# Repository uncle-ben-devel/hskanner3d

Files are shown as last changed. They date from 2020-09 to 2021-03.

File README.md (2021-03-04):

<p align="center">
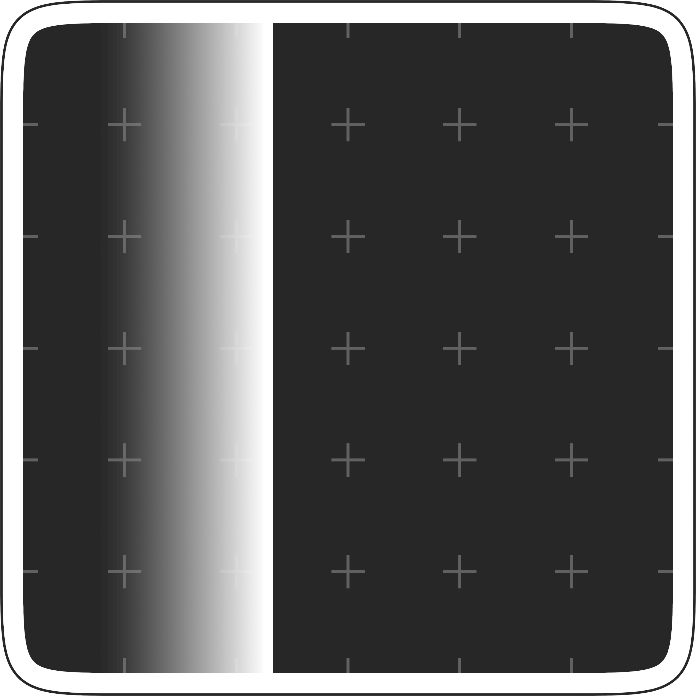
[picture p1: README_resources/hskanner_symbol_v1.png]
  
</p>

# HSkanner3D
3D scanning using a network of Raspberry Pies with camera modules and photogrammetry. This project is funded and overseen by Hochschule Karlsruhe - Technik und Wirtschaft and developed by Benedikt Reinberger. It involves the design and assembly of a complete 3D scanner (hardware and software). If you want to build your own, this may be a good starting point.

## HSkanner3D system architecture
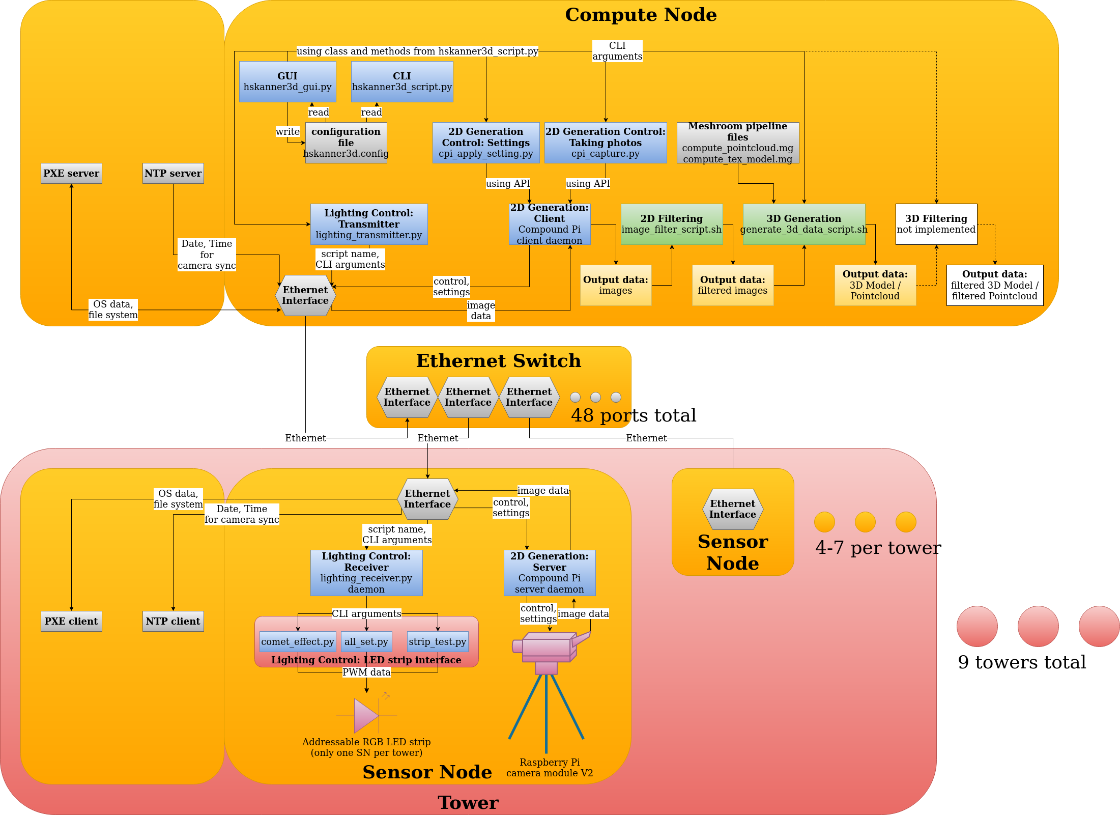
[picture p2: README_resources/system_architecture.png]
HSkanner3D system architecture


## The Scanner in the Lab in Karlsruhe
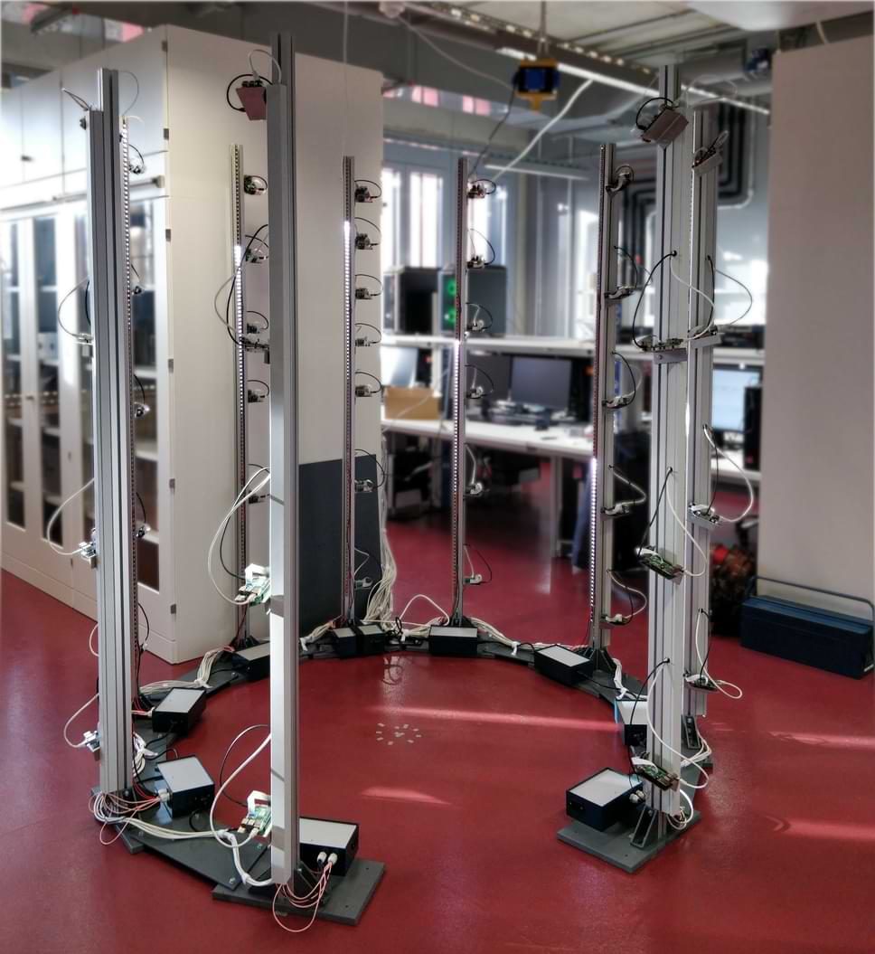
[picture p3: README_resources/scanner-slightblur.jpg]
HSkanner3D camera array


# Setup
## Hardware
To run your own instance of HSkanner3D or to set it up from scratch, first gather the required hardware.

*   PC with NVidia graphics card (needed for photogrammetry software Meshroom, uses CUDA exclusively)
*   keyboard, mouse, monitor for interfacing with the PC
*   one or more Raspberry Pi 4, Model B
*   one SD card, 16GB is plenty
*   one or more ethernet cable(s)
*   an ethernet switch with at least one interface for each Raspberry Pi and the PC (unmanaged is fine)

## Naming Conventions
First, some naming conventions.

*   the PC will run computation of the 3D model, so it is the compute node (**CN**)
*   the PC will run networking and camera array control, so it also is the array server (**AS**)
*   the Raspberry Pies will be connected to the camera sensors and are used to interface the cameras to the network, so they are sensor nodes (**SN**)
*   the SN are attached to metal structures to keep them suspended at a calculated height and angle. The metal structures are called **tower**s.
*   for each tower, there is one SN controlling the RGBW led strip for lighting and light effects. That one also is a lighting node (**LN**).

# Expert Installation Guide
*   install Ubuntu 18.04 on the PC.
*   install the required software by running
```
    sudo add-apt-repository -y ppa:waveform/ppa && sudo apt-get update && sudo apt-get install -y git meshlab python3-tk ntp python-pip python3-pip python3.7 compoundpi-client && pip install setuptools
```
*   set up the NTP server by running
```
    echo "broadcast 192.168.128.255" | sudo tee -a /etc/ntp.conf
    echo "server 127.127.1.0" | sudo tee -a /etc/ntp.conf
    echo "fudge 127.127.1.0 stratum 10" | sudo tee -a /etc/ntp.conf
```
*   then, edit /etc/ntp.conf to remove the "limited" option from the lines
```
    restrict -4 default kod notrap nomodify nopeer noquery limited
    restrict -6 default kod notrap nomodify nopeer noquery limited
    ->
    restrict -4 default kod notrap nomodify nopeer noquery
    restrict -6 default kod notrap nomodify nopeer noquery
```
*   from this repo, execute
```
    /installation_setup/pxe_setup/pxe_setup_script_static.sh
```
*   download RaspiOS buster lite armhf 2020-02-13 (2020-12-04 will work, too), then flash it to a micro SD card.
*   copy bootloader-flash-utils and cpi_setup from  the /installation_setup directory of hskanner3d to /home/pi on the rootfs.
*   then, copy over the 00_lighting_control directory from the /processing_chain of hskanner3d.
*   on the Raspberry Pi, execute
```
    /bootloader-flash-utils/flash_bootloader.sh
```
*   to flash the bootloader to one that can boot PXE. This script is made for automation. Add a cron job @reboot if you want to flash multiple Raspberry Pies headless.
*   make sure you have internet access on the Pi, then execute
```
    /cpi_setup/cpi_server_SN_setup.sh
```
*   then install the software required for the lighting to work using
```
    sudo apt-get install -y python3-pip python3.7 python3-rpi.gpio
    sudo pip3 install adafruit-circuitpython-neopixel rpi_ws281x
```
*   to enable the lighting control at boot, run
```
    crontab -e
```
*   and add
```
    @reboot sudo python3.7 /home/pi/00_lighting_control/lighting_receiver.py
    @reboot sudo service ntp stop && sudo ntpd -gq && sudo service ntp start
```
*   or equivalent, then save and exit.
*   enable the camera interface on the Pi.
*   mount the micro SD card on the PC and execute
```
    /installation_setup/pxe_setup/pxe_refresh_OS.sh
```
*   look at the config file in /processing_chain and modify the variables to suit your needs (keeping the data types).
*   reboot the PC
*   connect and power up the Raspberry Pies.
*   start the GUI from /processing_chain using python3.7.

# Beginner Installation Guide
## Operating System Setup
The HSkanner3D software is designed around the linux family of operating systems, thus we will be installing a linux distro on our PC to turn it into the CN and AS.

*   go to [the download page for Ubuntu 18.04](https://releases.ubuntu.com/18.04) and download the Ubuntu 18.04 .iso (HSkanner3D is known to work with Ubuntu 18.04 - other distros or versions may work, but 18.04 has all the majority of required software in the repositories or otherwise easily accessible). I recommend Ubuntu because it has the option to easily install and run the proprietary NVidia driver, which is needed for smooth operation.
*   on Windows, download [Rufus](https://rufus.ie/downloads/) or a similar tool and use it to flash the .iso to a USB medium from which we'll boot and install the OS.
*   on Linux, you can use dd to flash the .iso to an external installation medium using
```
    sudo dd if=/path/to/iso/name_of_iso.iso  of=/dev/sdx status=progress bs=4096 conv=fsync
    #    /dev/sdx should be substituted for the drive you want to flash the .iso to. Note that all partitions from that drive have to be unmounted first for dd to work.
```
*   insert the newly created usb installation medium into the PC and boot from it (you can look up the function key for the boot menu of your motherboard in the manual, or go into the BIOS and use boot override if available).
*   follow the instructions of the installation.
*   you will likely want to make a clean install, erasing everything on the OS disk before installing the new OS. Make sure you backed up any important files or partitions you want to keep beforehand, using a tool like [Clonezilla](https://clonezilla.org/downloads.php) for partitions and OS installs, or just copying the files to external media. I chose the minimal install, but either one should be fine. You can leave the boxes for third parties and updates unticked, we will deal with those manually.
*   to make networking easier, I recommend getting internet into the PC by using a different network interface than the one connected to the scanning array. The easiest way to do this is to use a smartphone connected to the PC using USB tethering. To do that, on your smartphone running Android, go to Settings > Network and Internet > Hotspot and tethering and toggle the USB tethering option while the phone is connected to the internet by the means of WiFi. Note that you have to toggle it every time the PC is rebooted.
*   if you chose Ubuntu 18.04, you will have to manually enable the proprietary NVidia drivers after the first boot. Press the Windows (Super) key on the keyboard and type "Software & Updates" to search for it. Click on the first result and navigate to the "Additional drivers" tab, then select the latest proprietary driver and install it.
## Software Install on CN
*   now that we have internet access on the PC, it is time to install the software.
*   open a terminal by pressing the Windows (Super) key, then type "terminal". Click on the icon or press enter.
*   first, we will install git, a version control system I used when I developed the software. This will be used to download all the project files to the target machine. To do that, type
```
    sudo apt-get install -y git
```
*   into the terminal and press enter.
*   now that git is installed, we will download the project files by execution of
```
    git clone https://github.com/uncle-ben-devel/hskanner3d.git
```
*   this will create the development folder of the project on the PC at the home directory root. (/home/your-username-here/)
*   now you can open this file (README.md) in a text editor of your choice and copy the commands directly instead of typing them out. You can do that by selecting the text with the mouse, then mousewheel clicking inside the terminal.
*   install the required software by execution of the following line:
```
    sudo add-apt-repository -y ppa:waveform/ppa && sudo apt-get update && sudo apt-get install -y meshlab python3-tk ntp python-pip python3-pip python3.7 compoundpi-client && pip install setuptools 
    # meshlab: used as 3D data visualizer
    # python3-tk: python3 library for GUI development
    # ntp: service for time sync over the network
    # python-pip: source for python2.x software
    # python3-pip: source for python3.x software
    # python3.7: the version of python that is verified to work with all the involved software and scripts. Other versions may work, but are not tested.
    # compoundpi-client: part of the image capture software running on the AS.
```
*   enter the password if prompted.
*   we need additional software that is not provided within the Ubuntu packages. Namely, [Meshroom (Version 2019 2.0 is known to work)](https://www.fosshub.com/Meshroom-old.html). Download it using the provided link, then move the folder named 'Meshroom-2019.2.0-linux' to /home/your-username-here/Documents/software. If the directory does not exist yet, create it. Alternatively, you can move it wherever you like and change the meshroomroot variable in the hskanner3d.config file. If you choose to use a version of Meshroom that is different from 2019.2.0-linux, make sure to correct this path in the config file as well.
*   to add the Raspberry Pi camera module to the camera database, replace the cameraSensors.db that comes with Meshroom (/aliceVision/share/aliceVision) with the one from /installation_setup.
*   if you want to be able to open the design files (CAD and simulation), you will need [Freecad 0.19](https://github.com/FreeCAD/FreeCAD/releases/tag/0.19_pre) with the Assembly4 and SheetMetal workbenches (Freecad 0.18 will NOT work since it can not open multiple project files at once) and [Blender 2.90.0](https://github.com/blender/blender/releases/tag/v2.90.0) with the MDLab plugin and the [demo assets](https://github.com/animate1978/MB-Lab-DemoAssets).
*   to set up the array network, search for 'Network' and click on the one under the 'Settings' category. First, click on the gear by PCI Ethernet to get into the settings of the on-board ethernet. Under the 'IPv4' tab, select 'Manual' for IPv4 Method and enter 192.168.128.2 as Address, and 255.255.255.0 as Netmask. Leave the Gateway empty. Disable IPv6 in its tab by selecting the 'Disable' option for 'IPv6 Method'. Toggle the interface on and off to apply the new settings.
*   set up the NTP server by running
```
    echo "broadcast 192.168.128.255" | sudo tee -a /etc/ntp.conf
    echo "server 127.127.1.0" | sudo tee -a /etc/ntp.conf
    echo "fudge 127.127.1.0 stratum 10" | sudo tee -a /etc/ntp.conf
```
*   this will broadcast the time on the subnet 192.168.128.0/24. Additionally, if time can not be obtained from the internet, it will use the internal clock instead.
*   then, edit /etc/ntp.conf to remove the "limited" option from the lines
```
    restrict -4 default kod notrap nomodify nopeer noquery limited
    restrict -6 default kod notrap nomodify nopeer noquery limited
    ->
    restrict -4 default kod notrap nomodify nopeer noquery
    restrict -6 default kod notrap nomodify nopeer noquery
```
*   this will ensure that time will be synchronized even if there are more than three clients.
*   make sure the PC has internet connection. Then, to enable PXE (booting the SNs over network) on the PC (AS) side, go to /installation_setup/pxe_setup. Afterwards, rightclick in the directory and select 'open in terminal' and execute
```
    ./pxe_setup_script_static.sh
```
*   this script sets up a DHCP server, a PXE server, fixes some common issues, and lays the groundwork for the SN to be able to boot from the ethernet interface. The DHCP server gives IP addresses from 192.168.128.100 to 192.168.128.200 to its clients. Make sure to change that when you have more than one hundred SN.
## Software install on SN (and LN)
*   download [RaspiOS buster lite armhf, .zip file](https://downloads.raspberrypi.org/raspios_lite_armhf/images/raspios_lite_armhf-2020-12-04), then flash it to a micro SD card. I tested the 2020-12-04 as well as the 2020-02-13 version, and both work. To help making flashing using dd easier, you can use the 'Disks' utility in Ubuntu. First, unmount all partitions on the SD card by clicking on them and then on the sqare icon below the partitions. After that, you can format it by clicking on the three horizontal lines > Format Disk ... > Format ... > Format. You can also get the device lettering from here (/dev/sdX).
*   once it is flashed, open the file browser and navigate to /media/your-username-here/boot and create an empty file called 'ssh' by opening a terminal there and executing
```
    sudo touch ssh
```
*   this enables us to remote into the Raspberry, omitting the use of a screen and keyboard.
*   next, navigate to /media/your-username-here/rootfs/etc and execute
```
    sudo nano dhcpcd.conf
```
*   then, add the lines
```
    interface eth0
    static ip_address=192.168.128.10/24
```
*   to the end of the file to set a static IP for the Pi. This makes it much easier to remote into it. Save the changes with Ctrl + S, then exit the editor using Ctrl + X.
*   navigate to /media/your-username-here/rootfs/home/pi, then copy over bootloader-flash-utils and cpi_setup from  the /installation_setup directory of hskanner3d.
*   then, copy over the 00_lighting_control directory from the /processing_chain of hskanner3d.
*   after the files have been copied over, you can eject the SD card and insert it into the Raspberry Pi.
*   power up the Raspberry Pi and connect it to the network.
*   open up a terminal on the PC (AS), and connect to the Pi using ssh:
```
    ssh pi@192.168.128.10
```
*   the password is raspberry.
*   first, we need to flash a bootloader to the Pi that will allow it to boot over the network. To do that, go to the /bootloader-flash-utils directory using cd
```
    cd ~/bootloader-flash-utils
```
*   hint: you can use tab for autocompletion.
*   then, execute
```
    sudo ./flash_bootloader.sh
```
*   the system will reboot and sever the ssh connection. Reconnect to it. If you want to flash multiple Pies, add a cron job @reboot that executes the flashing script. It will flash, do the mandatory reboot, then shut down.
*   once you are reconnected, you'll need internet access for the Raspberry. You can use USB tethering again. Test for internet connection using
```
    ping www.google.com
```
*   if you can't reach it, the Pi likely tries to access the internet using the ethernet interface, the local network. To circumvent this, execute
```
    sudo ip route delete default
```
*   make sure you have internet access, then change directory (cd) to ~/cpi_setup, then execute
```
    ./cpi_server_SN_setup.sh
```
*   then install the software required for the lighting to work using
```
    sudo apt-get install -y python3-pip python3.7 python3-rpi.gpio
    sudo pip3 install adafruit-circuitpython-neopixel rpi_ws281x
```
*   to enable the lighting control at boot, run
```
    crontab -e
```
*   and add
```
    @reboot sudo python3.7 /home/pi/00_lighting_control/lighting_receiver.py
    @reboot sudo service ntp stop && sudo ntpd -gq && sudo service ntp start
```
*   or equivalent, then save and exit. The second line is to force a NTP synchronization at boot which is required for compound pi synchronized capture.
*   next, we will remove the static IP we set for easy SSH. Execute
```
    sudo nano /etc/dhcpcd.conf
```
*   and delete the last two lines we added earlier.
*   enable the camera interface using
```
    sudo raspi-config
```
*   and navigating to Interfaces > Camera > enable
*   we can now shut down the Raspberry Pi using
```
    sudo shutdown now
```
*   and remove the micro SD card.
## Last steps for PXE booting
*   insert the SD card into the PC. Then, navigate to the /installation_setup/pxe_setup directory from hskanner3d and execute
```
    ./pxe_refresh_OS.sh
```
*   this script backs up the current OS setup, then takes the OS install from a SD card and copies it onto the local disk. Afterwards, it formats it in a way that wakes it compatible with network booting.
*   After the script has been executed, reboot. You can also remove the SD card now.
*   Powercycle the Raspberry Pi AFTER the PC has booted and been running for a little while. It should now boot from the network. To verify, execute
```
    cat /var/lib/misc/dnsmasq.leases
```
*   if there is no output, nothing has happened (yet). If everything goes smooth, the third field will have an IP address that was assigned to a Pi. The third field will say "raspberrypi" (the hostname of the device). The green status LED of the Pi should cycle between blinking fast twice, and pausing for about a second after it has booted with PXE. The boot may take a while (sometimes minutes), depending on the order the bootloader looks for PXE files on the network share.
# Using HSkanner3D
*   look at the config file in /processing_chain and modify the variables to suit your needs (keeping the data types).
```
The [default] section provides defaults for all other sections. It is loaded by pressing the "load defaults" option in the GUI.
The [custom] section is loaded on GUI startup and is used as persistant storage for the user settings.
    meshroomroot        is the complete path from filesystem root to the root of meshroom (the first folder that contains files other than a single folder)
    pipe_file_hq        is the name of the meshroom pipeline file that will be used when the "high quality" option for computation is chosen in the GUI.
    pipe_file_fast      same as pipe_file_hq, but for the "fast" option.
    number_sensor_nodes the number of Raspberry Pies attached to the scanning array. This is used by compoundpi to stop scanning for more servers when the defined number of SN has been found. If the number of SN in the array is lower than this variable, compound pi will throw an assertion error.
    network_subnet      is the local network we use for the scanning array, in CIDR-notation. It's recommended you don't change this, since this is not the only place you would need to change IP addresses to use a different network for the scanner. Read the setup if you want to look where IP addresses and ranges are set for this application.
    shutterspeed        is the shutterspeed of the Raspberry Pi camera module to be used. It is set in milliseconds and invalid values will result in the camera module using its default value. Since we want to scan humans, 1/50s...1/60s is a decent shutter speed.
    isosetting          is the ISO value of the camera module. Invalid values will result in the camera module using the highest or lowest possible setting (depending on whether you over- or undershot it), but writing the set ISO to the image metadata.
    whitebalance        is the whitebalance setting of the camera module. auto works well. If set values like tungsten are set, different camera modules will still have different color temperature in the end, with auto this problem is less visible.
    selftimer           is additional wait time in seconds before the shot is taken. It takes more time from pressing an action button (take images, 3d scan, ...) to the actual capture because of program overhead and general slowness of compoundpi. If selftimer is 0.0, the captures are not synchronized (on purpose) - the cameras will fire as soon as possible. That is usually good enough for a 3D scan of a human. One disadvantage of synced capture is that the clock of SN and AS need to be in sync, and there is no apparent way to easily check for that. Since the capture timing is set from the AS, it sets a timestamp at current time + selftimer time. If the SN are one hour behind, it will take one hour until a capture will happen. Don't set the selftimer too short (smaller than 0.1s), because Compound Pi will not be fast enough to react, yielding the error message 'Timestamp is in the past'. A value of 1.0s is usually a good time for decently fast reaction times with sync ong.
    rotation            rotation of the captured images in increments of 90 (degree). It's not required to rotate the images for Meshroom, it does not care. However, it is nicer to look at for humans.
    openfilebrowser     can be either 1 or 0 (enabled and disabled). If it's enabled, a file browser will open after image capture and the user can open the images to observe the captured material.
    view_mesh           can be either 1 or 0 (enabled and disabled). If it's enabled, Meshlab will open the generated 3D data for visualization after generation.
    strip_length        is the number of LEDs contained in a LED strip of a single tower.
    comet_tail_length   is length of in number of LEDs the comet effect (scanner idle decorative lighting) will have, minus one (the leading LED, the "comet").
    comet_brightness    is the brighness of the comet effect LEDs and can be from 0.0 to 1.0
    comet_r/g/b/w       are the color values of the comet, integers from 0 to 255.
    comet_sleeptime     is waiting time in seconds in between instances of the animation loop and thus defines how fast the effect will run through the strip.
    photo_light_r/g/b/w are the color values the LED strips will assume before and while taking photos, integers from 0 to 255.
```
*   now you can execute the GUI in a terminal or create a desktop shortcut (or modify the one supplied with the repo). The buttons and tabs of the GUI should be self-explanatory.
```
    python3.7 $HOME/hskanner3d/processing_chain/hskanner3d_gui.py
```

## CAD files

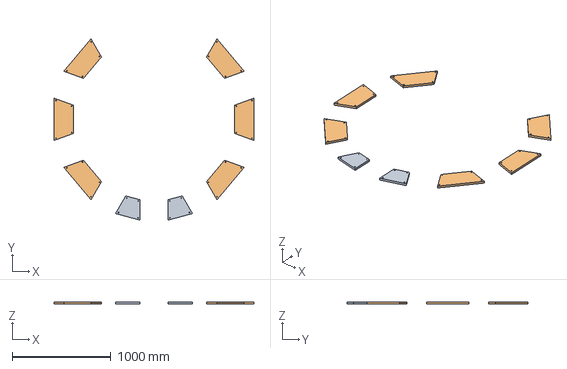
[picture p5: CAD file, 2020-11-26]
design/towers_scanner_cad/asm-array.FCStd
2030.3 x 1841.3 x 20.0 mm

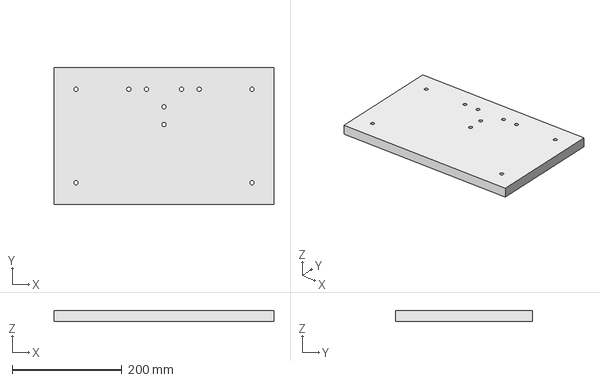
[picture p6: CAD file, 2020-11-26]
design/towers_scanner_cad/tower-parts.FCStd
400.0 x 250.0 x 20.0 mm

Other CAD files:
design/towers_scanner_cad/asm-tower-5c.FCStd
design/towers_scanner_cad/asm-tower-7c.FCStd
design/towers_scanner_cad/asm-tower-0c.FCStd
design/towers_scanner_cad/asm-tower-4c.FCStd
design/towers_scanner_cad/asm-tower-6c.FCStd

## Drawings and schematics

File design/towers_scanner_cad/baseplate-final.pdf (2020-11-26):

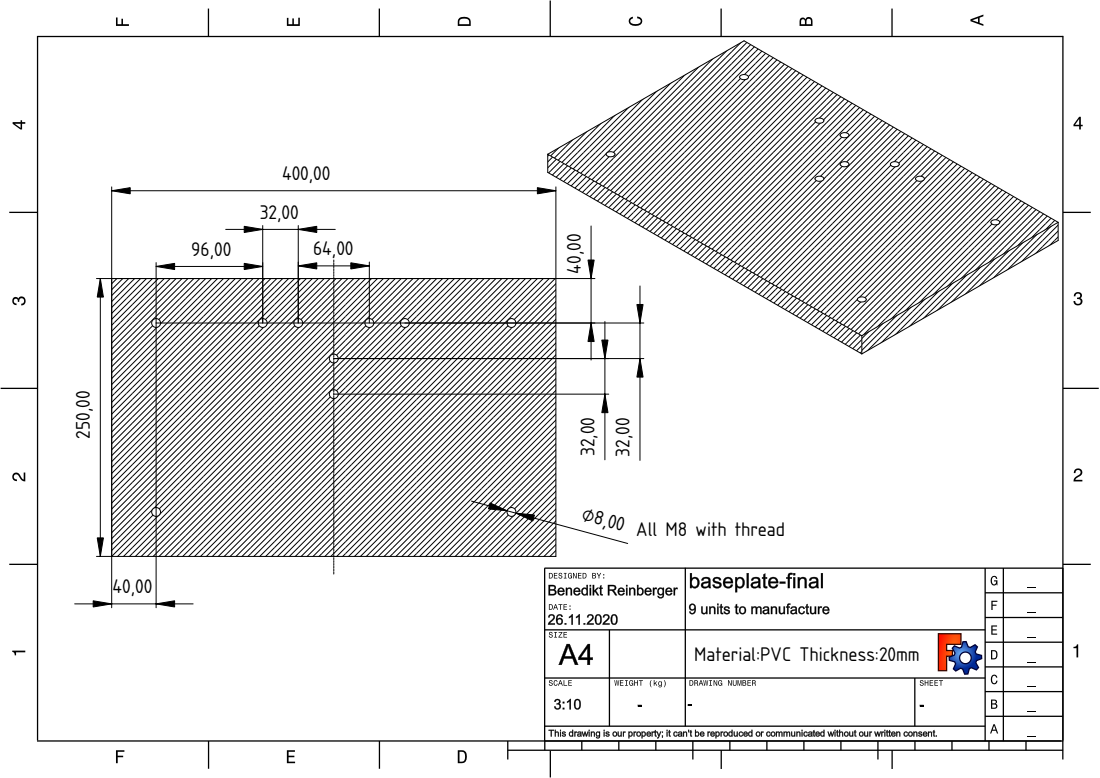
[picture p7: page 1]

⌀8,00 All M8 with thread

Material:PVC Thickness:20mm

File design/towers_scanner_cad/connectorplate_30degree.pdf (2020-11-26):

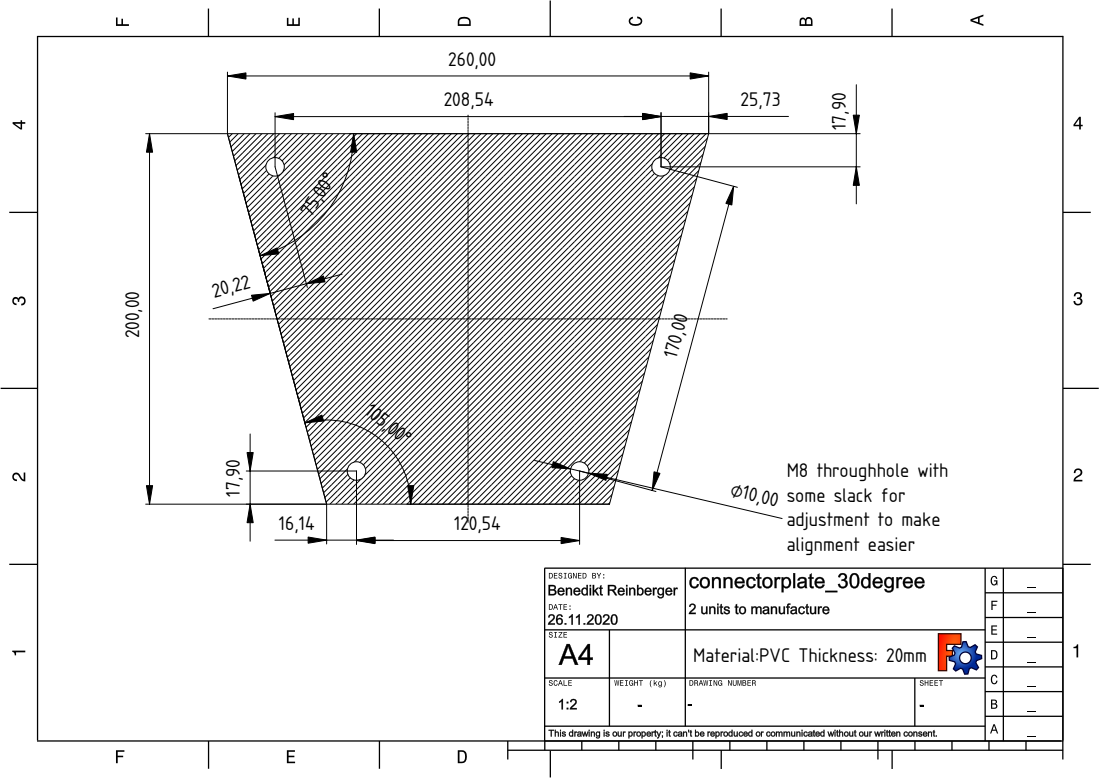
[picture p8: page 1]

M8 throughhole with
some slack for
adjustment to make
alignment easier

Material:PVC Thickness: 20mm

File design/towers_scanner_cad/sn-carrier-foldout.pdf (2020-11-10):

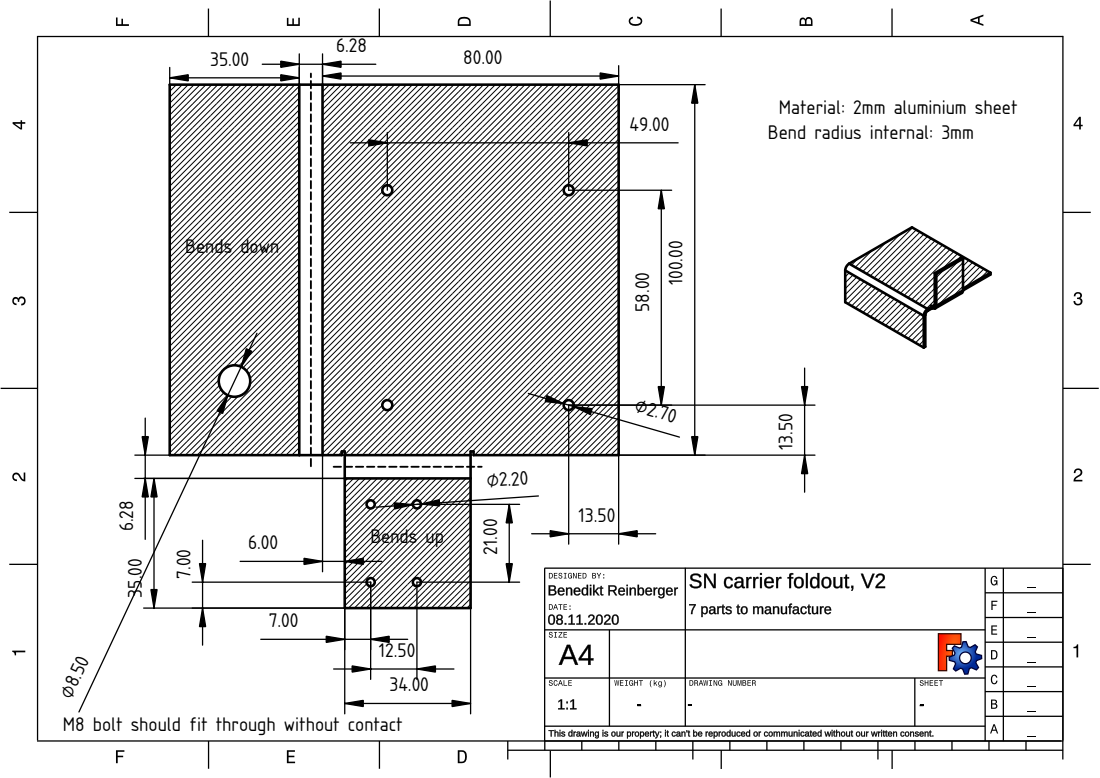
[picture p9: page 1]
Bends down; Bends up

Material: 2mm aluminium sheet
Bend radius internal: 3mm

M8 bolt should fit through without contact

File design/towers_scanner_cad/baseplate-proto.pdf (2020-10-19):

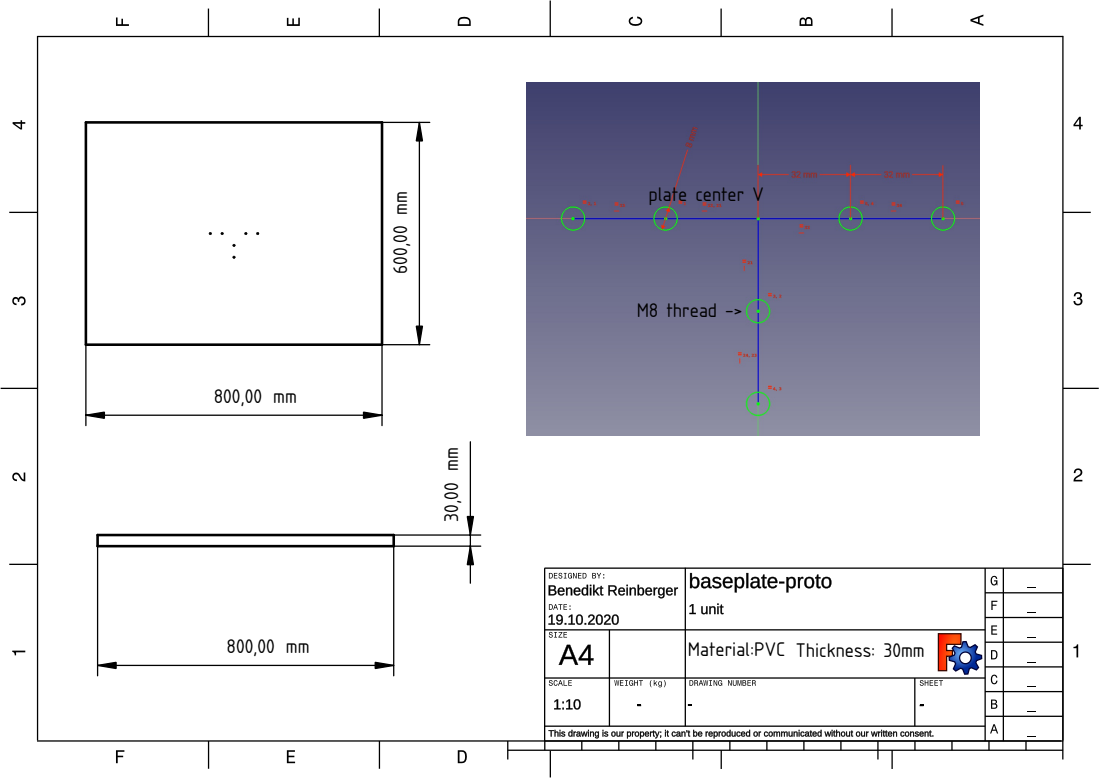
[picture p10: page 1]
M8 thread ->; plate center V

Material:PVC Thickness: 30mm

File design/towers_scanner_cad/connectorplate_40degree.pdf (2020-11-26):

4

3

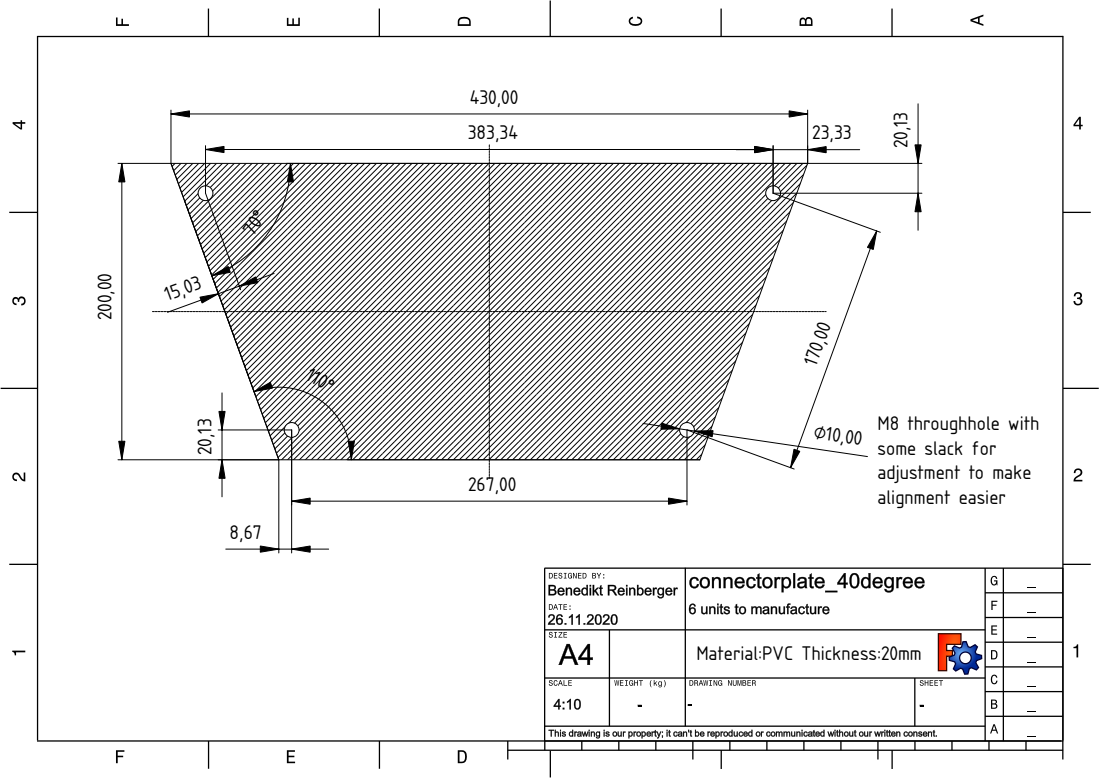
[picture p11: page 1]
aterial:P V; hick; 8 thro; h ole; with; slack for adjustment to m; alig n; sier

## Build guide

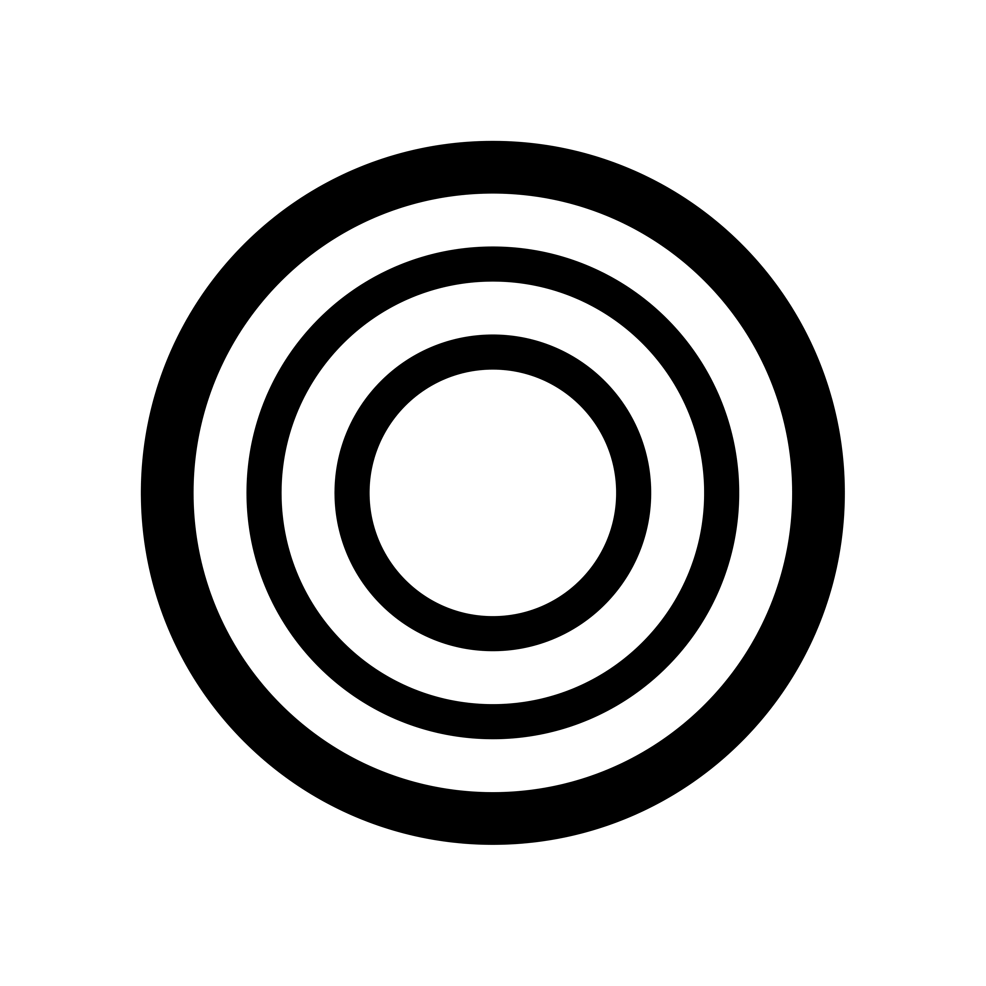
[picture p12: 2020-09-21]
design/position_estimation/CCTAGmarkersToPrint/00027-1.png

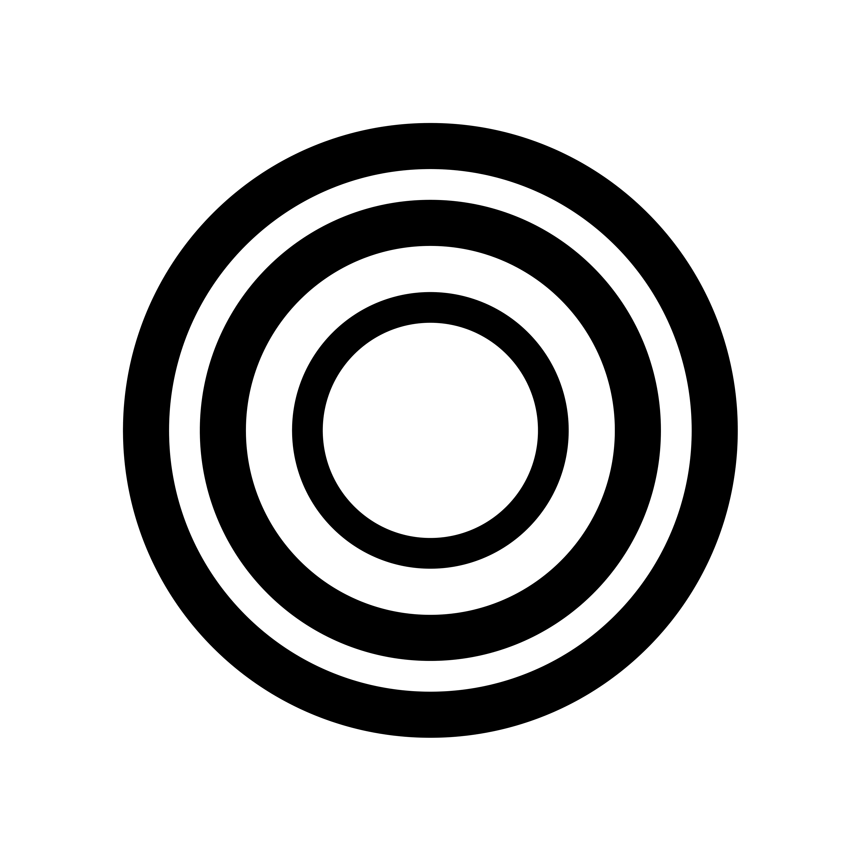
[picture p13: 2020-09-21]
design/position_estimation/CCTAGmarkersToPrint/00023-1.png

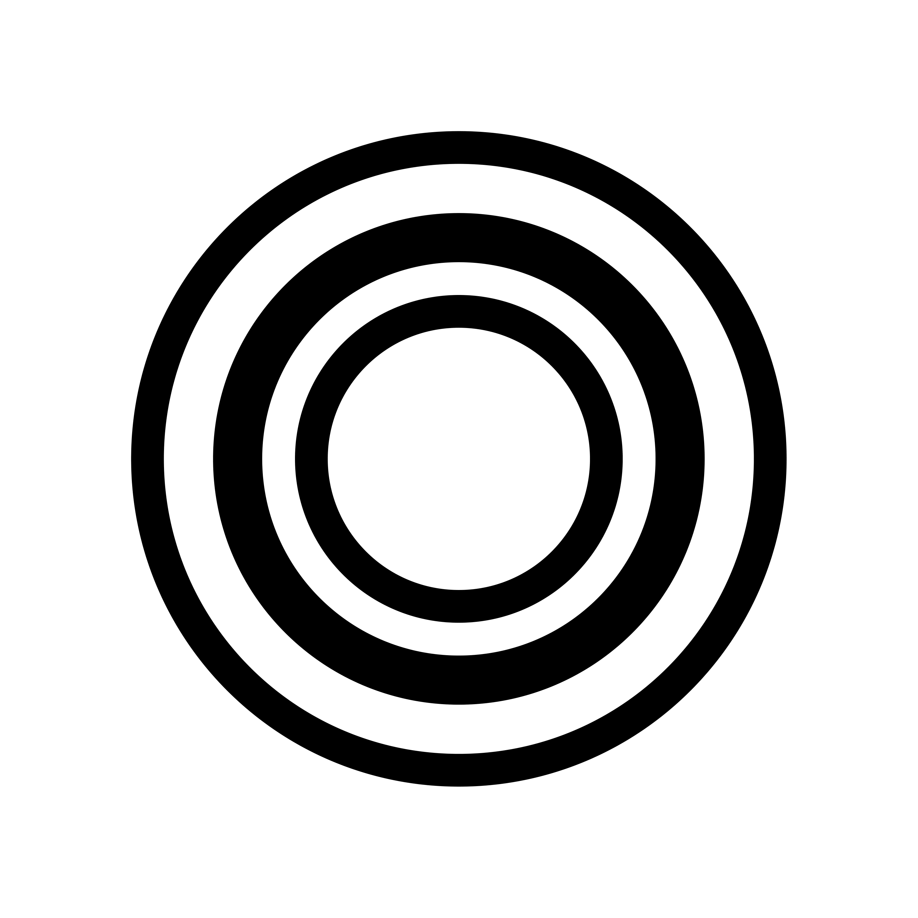
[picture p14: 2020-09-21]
design/position_estimation/CCTAGmarkersToPrint/00013-1.png

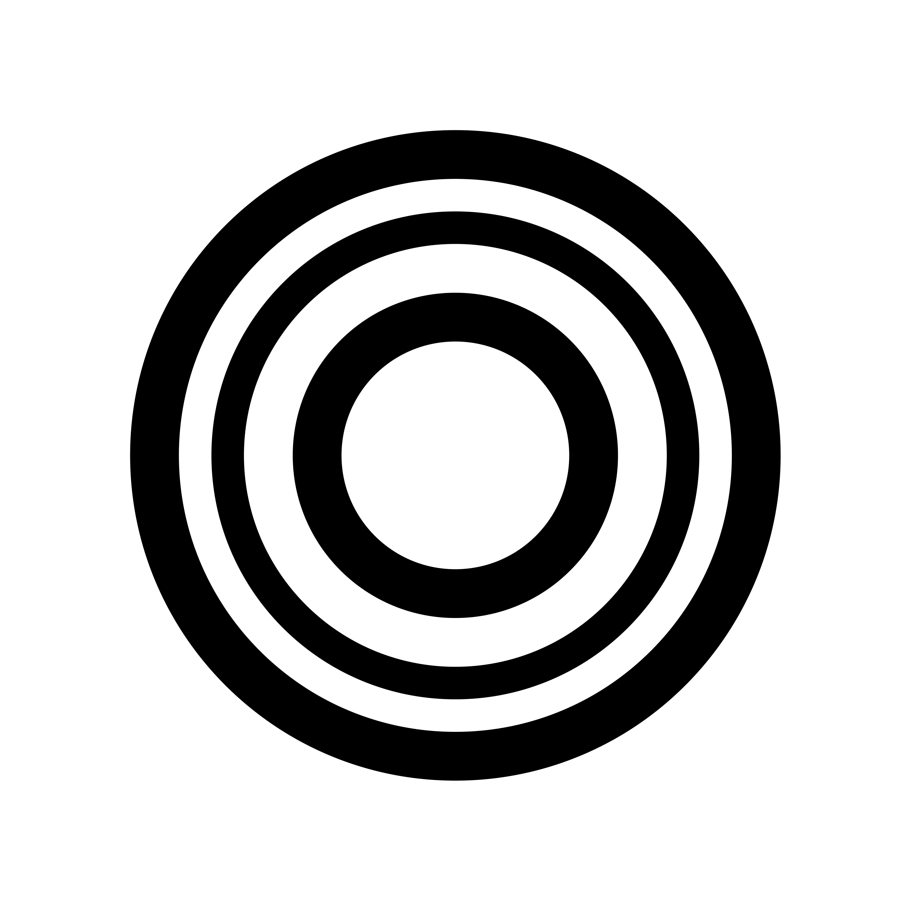
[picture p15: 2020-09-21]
design/position_estimation/CCTAGmarkersToPrint/00020-1.png

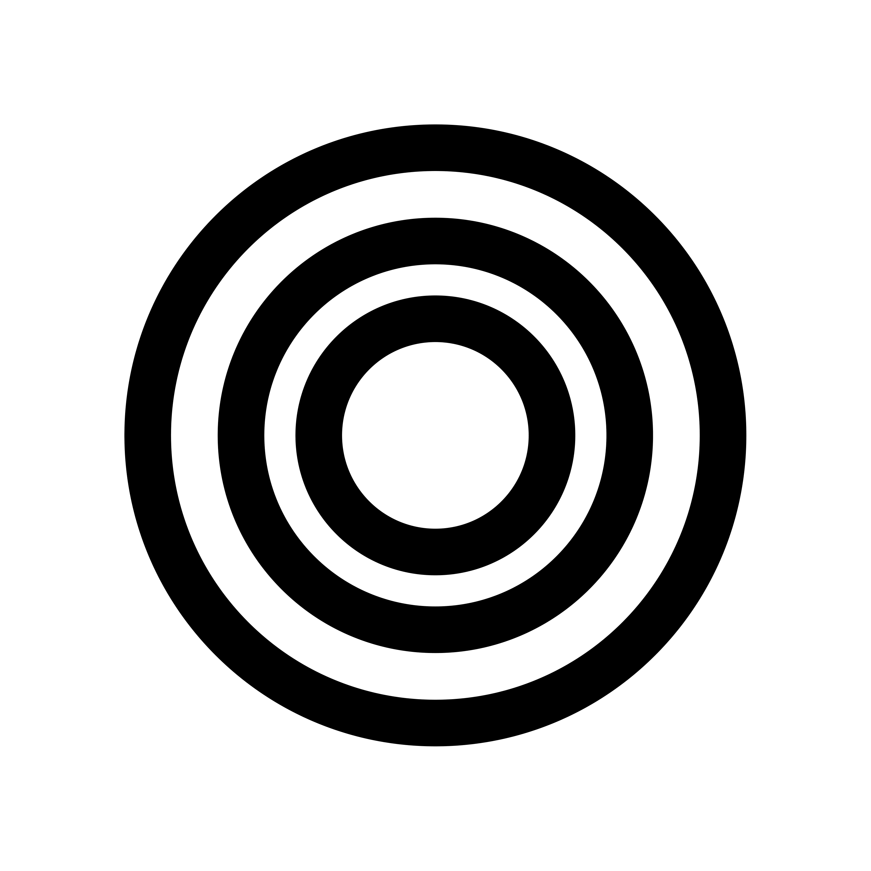
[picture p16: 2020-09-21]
design/position_estimation/CCTAGmarkersToPrint/00030-1.png

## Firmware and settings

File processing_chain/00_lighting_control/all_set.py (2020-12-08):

# Purpose
#   This script controls an RGBW-Strip with the data_in line attached to GPIO 18 on a Raspberry Pi.. All LEDs will be at the same user defined values.
####
# Usage
#   python3.7 all_set.py <int red_value> <int green_value> <int blue_value> <int white_value> <int number_leds>
#   color values can be 0...255 only.
#!/usr/bin/env python

import board
import neopixel
from sys import argv

# LED strip configuration:
LED_COUNT   = int(argv[5])      # Number of LED pixels.
LED_PIN     = board.D18      # GPIO pin
LED_BRIGHTNESS = 1
LED_ORDER = neopixel.GRBW # order of LED colours. May be GRB, RGB, GRBW, or RGBW

# Create NeoPixel object with appropriate configuration.
strip = neopixel.NeoPixel(LED_PIN, LED_COUNT, brightness = LED_BRIGHTNESS, auto_write=False, pixel_order = LED_ORDER)

strip.fill((int(argv[1]),int(argv[2]),int(argv[3]),int(argv[4])))
strip.show()

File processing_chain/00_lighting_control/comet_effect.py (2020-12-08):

# Purpose
#   This script controls an RGBW-Strip with the data_in line attached to GPIO 18 on a Raspberry Pi. It is used as the idle state of the LED strips and serves purely cosmetic purpose. It will run a tail of a  user defined length across the LED strip, using a user defined speed, color and brightness. The tail gets dimmer from origin to end.
####
# Usage
#   python3.7 comet_effect.py <int led_count> <int tail_length> <float led_brightness> <int red_value> <int green_value> <int blue_value> <int white_value> <float sleeptime>
#   color values can be 0...255 only. Sleeptime is additional wait time after each moving operation and is meant to slow the moving operation down.

#!/usr/bin/env python

from time import sleep
from sys import argv
import board
import neopixel

# LED strip configuration:
LED_COUNT   = int(argv[1])      # Number of LED pixels.
tail_len = int(argv[2]) # the tail will consist of tail_len-1 leds, with one led leading with 100% of what was set for the rgb values.
LED_PIN     = board.D18      # GPIO pin
LED_BRIGHTNESS = float(argv[3])  # LED brightness
LED_ORDER = neopixel.GRBW # order of LED colours. May be GRB, RGB, GRBW, or RGBW
# effect config
comet_r = int(argv[4])
comet_g = int(argv[5])
comet_b = int(argv[6])
comet_w = int(argv[7])
sleeptime = float(argv[8])    # change this value to adjust the speed of the effect. 0 is no wait in between cycles.

# Create NeoPixel object with appropriate configuration.
strip = neopixel.NeoPixel(LED_PIN, LED_COUNT, brightness = LED_BRIGHTNESS, auto_write=False, pixel_order = LED_ORDER)

strip.fill((0,0,0,0))   # clear strip before use

# Calculate all values for the LEDs just once. After that, it can be used as a shift register.
def comet_init(tail_len):
    for jj in range(tail_len):
        cc = (tail_len - jj) / (tail_len * (jj + 1))  # brightness factor for tail. Since brightness does not scale linearly, i chose (n-x)/(n*(x+1)) for scaling, where n is the tail length and x is the distance from the brightest LED.
        strip[jj % LED_COUNT] = (int(comet_r*cc),int(comet_g*cc),int(comet_b*cc),int(comet_w*cc))

# Shift register shifting (MSB: strip[0], shifts to the left)
def comet_loop():
    global strip    # needs to be global for us to be able to address it. Passing it to the function does not really work - I tried that first.
    buf = strip[0]
    strip[0:LED_COUNT-1] = strip[1:LED_COUNT]   # weird python adressing. why not ([0:LED_COUNT-2] and [1:LED_COUNT-1]?)
    strip[LED_COUNT-1] = buf
    strip.show()

# this try-finally construct allows for controlled behaviour when we kill the script. The script runs in a permanent loop, and blocks other scripts from controlling the LEDs. So if we want to do something different with the LED strip, we kill this script and execute another.
try:
    comet_init(tail_len)
    while True:
        comet_loop()
        sleep(sleeptime)        
finally:
    strip.fill((0,0,0,0))
    strip.show()

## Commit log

2020-09-03 Cleaned up the bash scripts, Updated paths and working directory
    [mesh.obj, texturedMesh.obj]
2020-09-03 Configured .gitignore with i/o directories
    [mesh.obj, texturedMesh.obj]
2020-09-07 Added precise camera information to the sensors database, and changed fov to 79d since that is the diagonal fov of the sensor module v2. Accuracy of the scanning improved DRAMATICALLY
2020-09-14 Added Blender Project folder for camera and lighting placement
2020-09-21 Tested new camera heights with the 9T design
2020-10-07 Made a rough 3D model of one tower assy in Freecad 0.19
    [assy_4.FCStd]
2020-10-09 Modified base to enable more materials to be used for the walls
    [assy_4.FCStd]
2020-10-11 Added new design for SN carriers and supportblocks
    [assy_4.FCStd]
2020-10-12 Added a radius to the cutouts in the walls
    [assy_4.FCStd]
2020-10-14 Added Version 2 of the tower design, now made using aluminium profiles.
    [asm_tower_v2.FCStd, assy_4.FCStd]
2020-10-15 Made an assembly for the completed array
    [asm_array_v2.FCStd, asm_tower_v2.FCStd]
2020-10-16 Changed CAD project structure to be more modular, added Lab as a reference to the finished array.
    [asm-array.FCStd, asm-tower-0c.FCStd, asm-tower-4c.FCStd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]
2020-10-19 Optimized SN carrier and techdraw document, added prototype baseplate for single tower use.
    [tower-parts.FCStd]
2020-11-02 changed folder layout and changed all bash scripts to use the config file for configuration instead of flags. should allow a later gui to just write a config file and then execute a script, keeping i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
    [asm-array.FCStd, asm-tower-0c.FCStd, asm-tower-4c.FCStd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]
2020-11-04 Added local files to control a neopixel GRBW LED strip from a raspberry pi.
2020-11-08 Changed design of SN carrier for the raspberry pi i/o to be more accessible.
    [tower-parts.FCStd]
2020-11-09 Made execution of local python scripts via a socket server an client possible.
2020-11-10 Adjusted the sn-carrier-foldout file to present a 3d view.
    [asm-tower-0c.FCStd, tower-parts.FCStd]
2020-11-16 Streamlined code, not everything is python yet, but will be in the next commit. Changed many scripts to python and overhauled config file structure and general architecture of the processing chain co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
2020-11-26 Finalized CAD design for scanning array
    [asm-array.FCStd, asm-tower-0c.FCStd, asm-tower-4c.FCStd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]
2020-12-08 Added a lot of comments to the processing chain scripts for documentation. Also cleaned some of them up.
2021-02-11 Added scaling option to image filtering and the GUI
2021-02-15 Fixed hskanner3d_script interfacing with the 2d filtering script
